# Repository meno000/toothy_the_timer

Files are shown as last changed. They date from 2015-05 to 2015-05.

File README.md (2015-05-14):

# toothy_the_timer
A little PCB project that helps kids brush teeth for the proper amount of time.

It uses the Atmet Attiny85 along with some shift registers and various LEDs, etc.

Schematics were created in KiCad. Gerbers are available if you'd like to send the board out to a fab house.

Note that this repository does not have a bootloader in it. You'll have to find/roll your own. This is mainly to avoid any issues with USB VID/PID numbers.

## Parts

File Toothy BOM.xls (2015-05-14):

Item # | Description | SMD or Through Hole | Mouser Part # | Mouser Mfg | Mouser Mfg Part # | Mouser $ | Digikey Part # | Digikey Mfg | Digikey Mfg # | Digikey $ | Distributor Selected | Quantity | Cost | Total Cost
PCB | PCB | N/A | N/A | N/A | N/A |  | N/A | N/A | N/A |  | DirtyPCBs | 1 | $2.50 | $2.50
Switches | Push Button Switches | SMD | 653-B3FS-1000 | Omron | B3FS-1000 | 0.455 | SW423CT-ND |  |  |  | Mouser | 3 | $0.46 | $1.36
USB | Micro USB Port - Female | SMD | 587-690-005-299-143 | EDAC | 690-005-299-143 | 0.198 |  |  |  |  | Mouser | 1 | $0.20 | $0.20
Diode | Power Diode | SMD | 625-RS1A-E3/5AT | Vishay | RS1A-E3/5AT | 0.99 |  |  |  |  | Mouser | 1 | $0.99 | $0.99
Capacitor | 10 uF | SMD | 77-VJ1206V106ZXQTBC | Vishay | VJ1206V106ZXQTW1BC | 0.049 |  |  |  |  | Mouser | 1 | $0.05 | $0.05
Capacitor | .1 uF | SMD | 77-VJ1206Y104KXXCBC | Vishay | VJ1206Y104KXXCW1BC | 0.033 |  |  |  |  | Mouser | 1 | $0.03 | $0.03
LED Resistor | 220 Ohm | SMD | 71-CRCW1206J-220-E3 | Vishay | CRCW1206220RJNEA | 0.008 |  |  |  |  | Mouser | 25 | $0.01 | $0.20
Pull Up Resistor | 10 kOhm | SMD | 71-CRCW1206J-10K-E3 | Vishay | CRCW120610K0JNEA | 0.03 |  |  |  |  | Mouser | 4 | $0.03 | $0.12
Attiny 85 | SOIC-8 Package | SMD | 556-ATTINY85-20SU | Atmel | ATtiny85-20SU | 1.22 |  |  |  |  | Mouser | 1 | $1.22 | $1.22
595 Shift | TSSOP/SOT-403 Package | SMD | 771-HC595PW112 | NSP | 74HC595PW,112 | 0.369 |  |  |  |  | Mouser | 3 | $0.37 | $1.11
ICSP Connection | 3x2 6 pin package | Through Hole | 517-30306-6002HB | 3M | 30306-6002HB | 0.52 |  |  |  |  | Mouser | 1 | $0.52 | $0.52
Regulator | 7805 LDO, .800 A. SOT-223 | SMD | 511-LD1117S50 | ST Micro | LD1117S50TR | 0.372 |  |  |  |  | Mouser | 1 | $0.37 | $0.37
LEDs | Various colors, 1206 | SMD | Various | Various | Various | 0.008 | Various | Various | Various | Various | Mouser | 25 | $0.01 | $0.20
Battery Connection | 2 pin | Through Hole | 538-70553-0036 | Molex | 70553-0036 | 0.633 |  |  |  |  | Mouser | 1 | $0.63 | $0.63
Battery Wire Connection | 2 pin | N/A | 538-50-57-9402 | Molex | 50-57-9402 | 0.293 |  |  |  |  | Mouser | 1 | $0.29 | $0.29
Crimp Terminal | 2 pin | N/A | 538-16-02-0096 | Molex | 16-02-0096 | 0.069 |  |  |  |  | Mouser | 2 | $0.07 | $0.14
Battery Pack | Battery Snap for 9V | N/A | 121-0424/I-GR | Eagle Plastic | 121-0424/I-GR | 0.39 |  |  |  |  | Mouser | 1 | $0.39 | $0.39
 |  |  |  |  |  |  |  |  |  |  |  |  | Total | $10.33
LEDs | Notes
Pink
Red | 1.8V, Need 220 Ohm R |  | 720-LHN974-KN-1 | Osram | LH N974-KN-1 | 0.08
Blue | 3V, Need 100 Ohm R |  | 859-LTST-C21TBKT | Liteon | LTST-C21TBKT | 0.16
Green | 2.6V |  | 720-LGN971-KN-1 | Osram | LG N971-KN-1
Purple
 |  |  | 121-0424/I-GR |  | 538-16-02-0096
 |  |  | Manufacturer Part #: |  | Manufacturer Part #:
 |  |  | 121-0424/I-GR |  | 16-02-0096

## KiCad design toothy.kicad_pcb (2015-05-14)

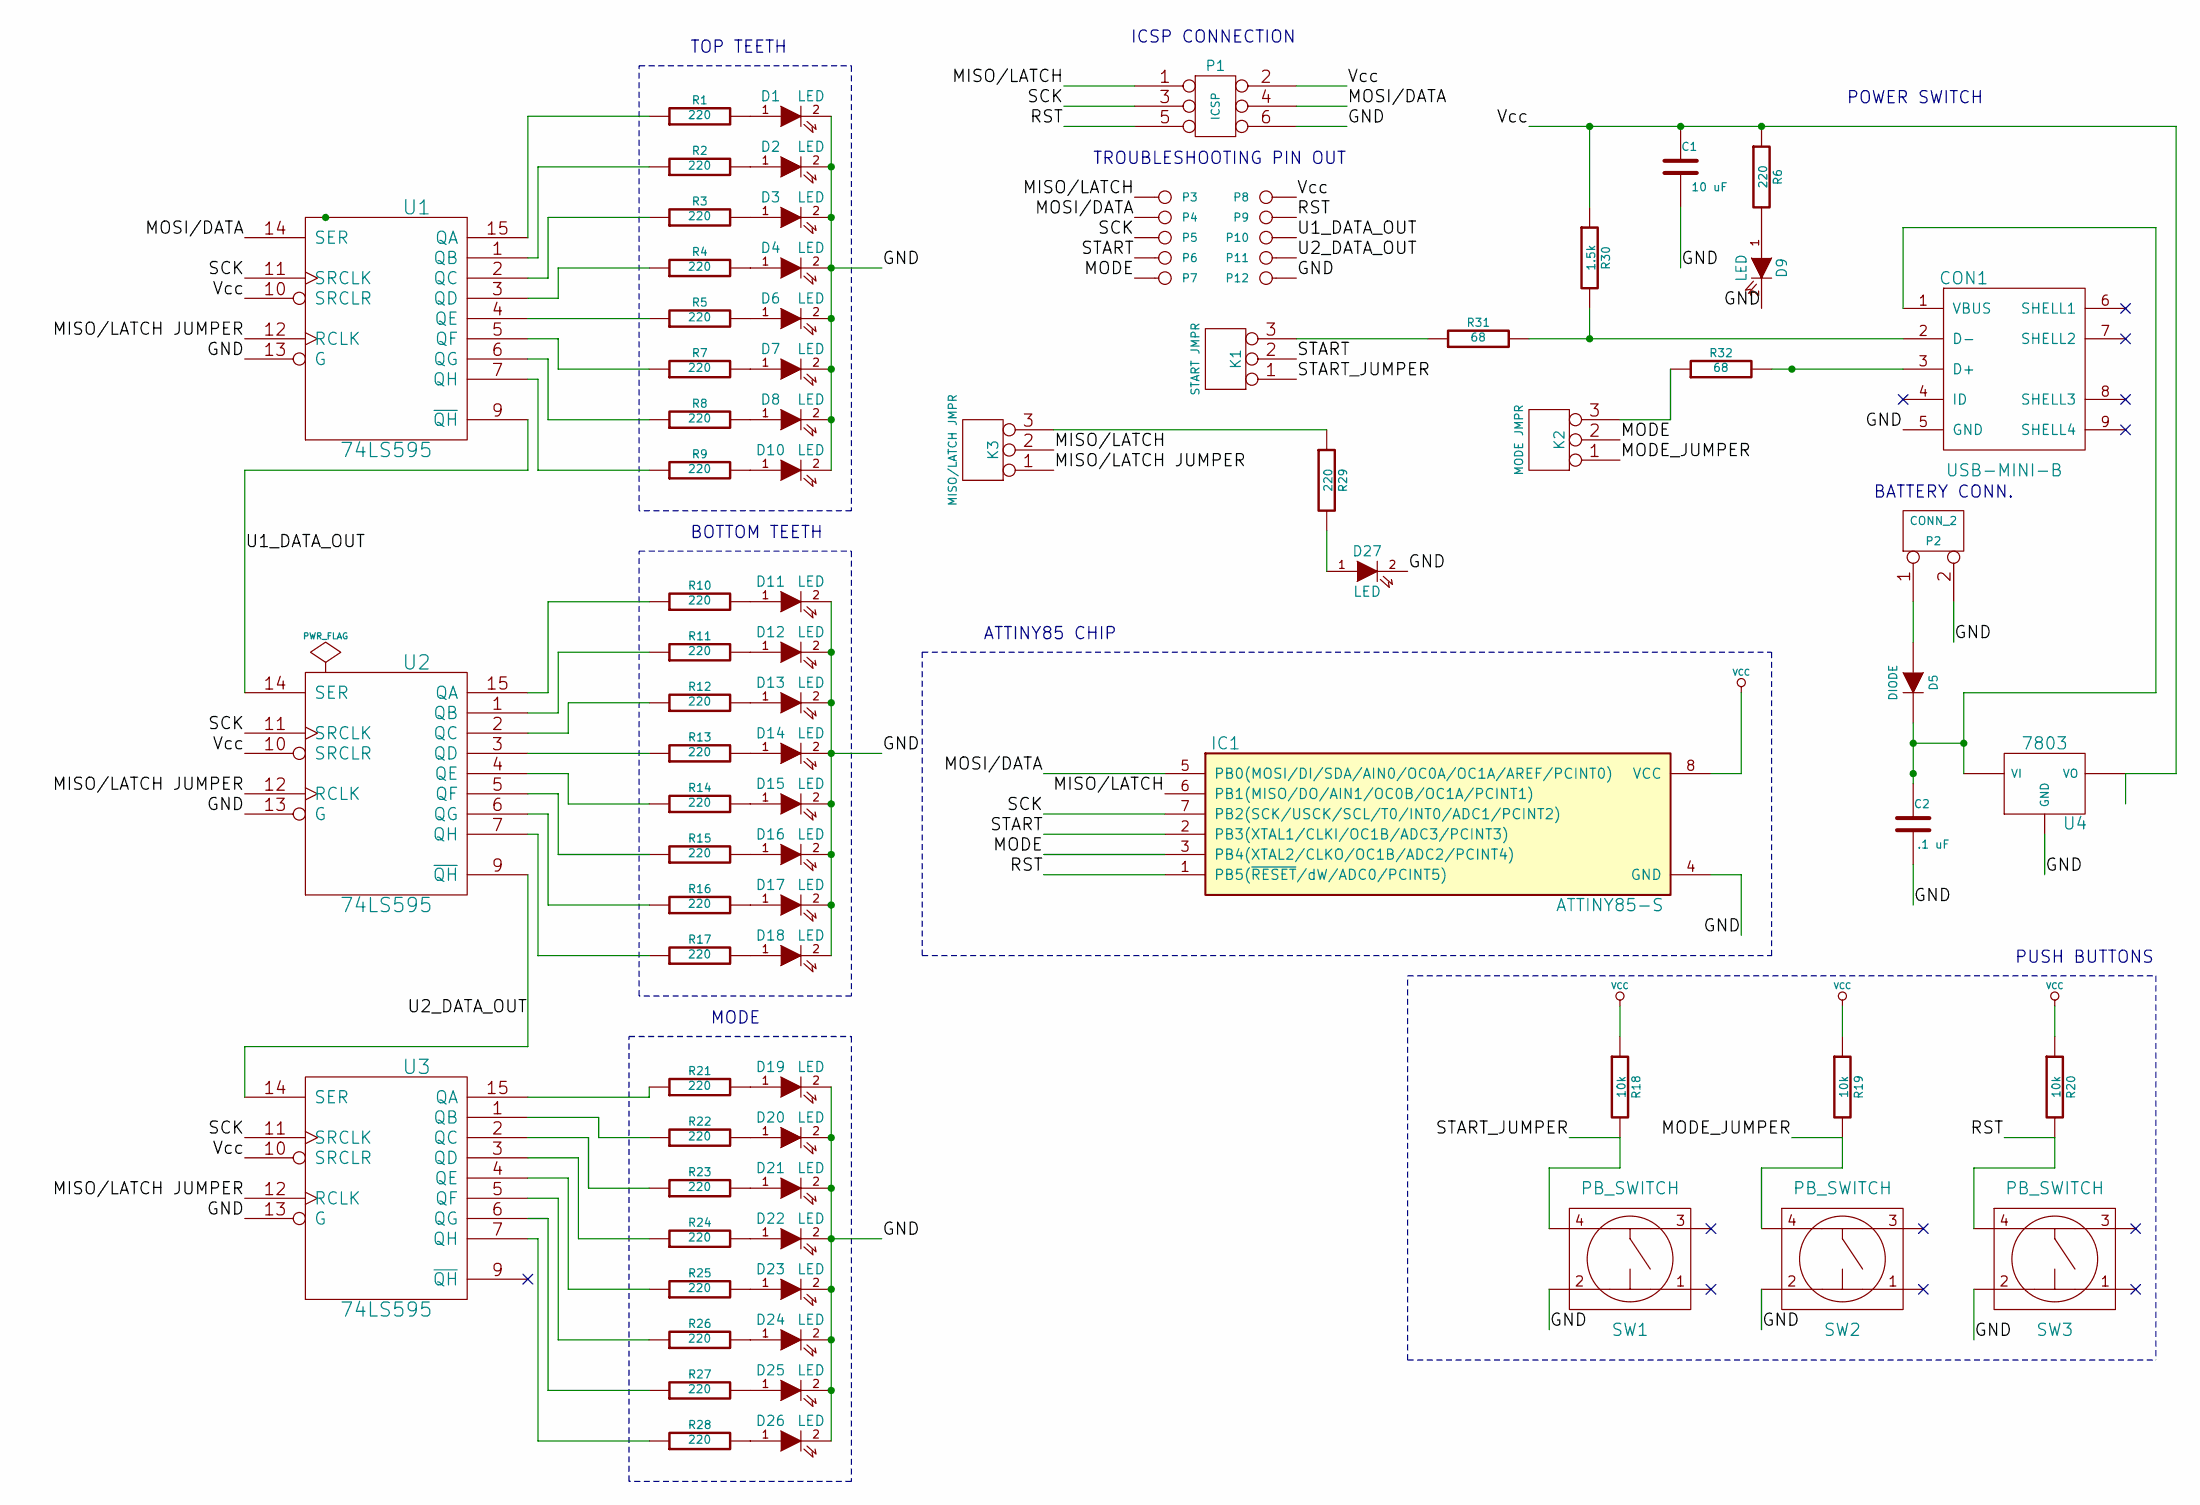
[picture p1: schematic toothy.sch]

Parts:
C1: 10 uF
C2: .1 uF
CON1: USB-MINI-B
D1, D2, D3, D4, D6, D7, D8, D9, D10, D11, D12, D13, D14, D15, D16, D17, D18, D19, D20, D21, D22, D23, D24, D25, D26, D27: LED
D5: DIODE
IC1: ATTINY85-S; SO8-200
K1: START JMPR
K2: MODE JMPR
K3: MISO/LATCH JMPR
P1: ICSP
P2: CONN_2
P3, P4, P5, P6, P7, P8, P9, P10, P11, P12: CONN_1
R1, R2, R3, R4, R5, R6, R7, R8, R9, R10, R11, R12, R13, R14, R15, R16, R17, R21, R22, R23, R24, R25, R26, R27, R28, R29: 220
R18, R19, R20: 10k
R30: 1.5k
R31, R32: 68
SW1, SW2, SW3: PB_SWITCH
U1, U2, U3: 74LS595
U4: 7803

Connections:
/MISO/LATCH: IC1.6 (PB1(MISO/DO/AIN1/OC0B/OC1A/PCINT1)), K3.2 (PM), P1.1, P3.1
/MISO/LATCH JUMPER: K3.1, U1.12 (RCLK), U2.12 (RCLK), U3.12 (RCLK)
/MODE: IC1.3 (PB4(XTAL2/CLKO/OC1B/ADC2/PCINT4)), K2.2 (PM), P7.1
/MODE_JUMPER: K2.1, R19.2, SW2.4
/MOSI/DATA: IC1.5 (PB0(MOSI/DI/SDA/AIN0/OC0A/OC1A/AREF/PCI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), P1.4, P4.1, U1.14 (SER)
/RST: IC1.1 (PB5(~RESET~/dW/ADC0/PCINT5)), P1.5, P9.1, R20.2, SW3.4
/SCK: IC1.7 (PB2(SCK/USCK/SCL/T0/INT0/ADC1/PCINT2)), P1.3, P5.1, U1.11 (SRCLK), U2.11 (SRCLK), U3.11 (SRCLK)
/START: IC1.2 (PB3(XTAL1/CLKI/OC1B/ADC3/PCINT3)), K1.2 (PM), P6.1
/START_JUMPER: K1.1, R18.2, SW1.4
/U1_DATA_OUT: P10.1, U1.9 (~QH), U2.14 (SER)
/U2_DATA_OUT: P11.1, U2.9 (~QH), U3.14 (SER)
GND: C1.2, C2.2, CON1.5 (GND), D1.2 (K), D2.2 (K), D3.2 (K), D4.2 (K), D6.2 (K), D7.2 (K), D8.2 (K), D9.2 (K), D10.2 (K), D11.2 (K), D12.2 (K), D13.2 (K), D14.2 (K), D15.2 (K), D16.2 (K), D17.2 (K), D18.2 (K), D19.2 (K), D20.2 (K), D21.2 (K), D22.2 (K), D23.2 (K), D24.2 (K), D25.2 (K), D26.2 (K), D27.2 (K), IC1.4 (GND), P1.6, P2.2 (PM), P12.1, SW1.2, SW2.2, SW3.2, U1.8 (GND), U1.13 (G), U2.8 (GND), U2.13 (G), U3.8 (GND), U3.13 (G), U4.GND
unnamed: D27.1 (A), R29.2
unnamed: CON1.2 (D-), R30.2, R31.2
unnamed: K2.3, R32.1
unnamed: D5.1 (A), P2.1
unnamed: K3.3, R29.1
unnamed: K1.3, R31.1
unnamed: R1.1, U1.15 (QA)
unnamed: R2.1, U1.1 (QB)
unnamed: R3.1, U1.2 (QC)
unnamed: R4.1, U1.3 (QD)
unnamed: C2.1, CON1.1 (VBUS), D5.2 (K), U4.VI
unnamed: CON1.3 (D+), R32.2
unnamed: R15.1, U2.5 (QF)
unnamed: R16.1, U2.6 (QG)
unnamed: R17.1, U2.7 (QH)
unnamed: R21.1, U3.15 (QA)
unnamed: R22.1, U3.1 (QB)
unnamed: R23.1, U3.2 (QC)
unnamed: R24.1, U3.3 (QD)
unnamed: R25.1, U3.4 (QE)
unnamed: R26.1, U3.5 (QF)
unnamed: R27.1, U3.6 (QG)
unnamed: R28.1, U3.7 (QH)
unnamed: R5.1, U1.4 (QE)
unnamed: R7.1, U1.5 (QF)
unnamed: R8.1, U1.6 (QG)
unnamed: R9.1, U1.7 (QH)
unnamed: R10.1, U2.15 (QA)
unnamed: R11.1, U2.1 (QB)
unnamed: R12.1, U2.2 (QC)
unnamed: R13.1, U2.3 (QD)
unnamed: R14.1, U2.4 (QE)
unnamed: D1.1 (A), R1.2
unnamed: D10.1 (A), R9.2
unnamed: D8.1 (A), R8.2
unnamed: D7.1 (A), R7.2
unnamed: D6.1 (A), R5.2
unnamed: D4.1 (A), R4.2
unnamed: D3.1 (A), R3.2
unnamed: D2.1 (A), R2.2
unnamed: D26.1 (A), R28.2
unnamed: D25.1 (A), R27.2
unnamed: D24.1 (A), R26.2
unnamed: D23.1 (A), R25.2
unnamed: D22.1 (A), R24.2
unnamed: D21.1 (A), R23.2
unnamed: D20.1 (A), R22.2
unnamed: D19.1 (A), R21.2
unnamed: D14.1 (A), R13.2
unnamed: D13.1 (A), R12.2
unnamed: D12.1 (A), R11.2
unnamed: D11.1 (A), R10.2
unnamed: D9.1 (A), R6.2
unnamed: D18.1 (A), R17.2
unnamed: D17.1 (A), R16.2
unnamed: D16.1 (A), R15.2
unnamed: D15.1 (A), R14.2
VCC: C1.1, IC1.8 (VCC), P1.2, P8.1, R6.1, R18.1, R19.1, R20.1, R30.1, U1.10 (SRCLR), U1.16 (VCC), U2.10 (SRCLR), U2.16 (VCC), U3.10 (SRCLR), U3.16 (VCC), U4.VO

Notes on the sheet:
TOP TEETH
BOTTOM TEETH
MODE
ATTINY85 CHIP
PUSH BUTTONS
ICSP CONNECTION
POWER SWITCH
BATTERY CONN.
TROUBLESHOOTING PIN OUT

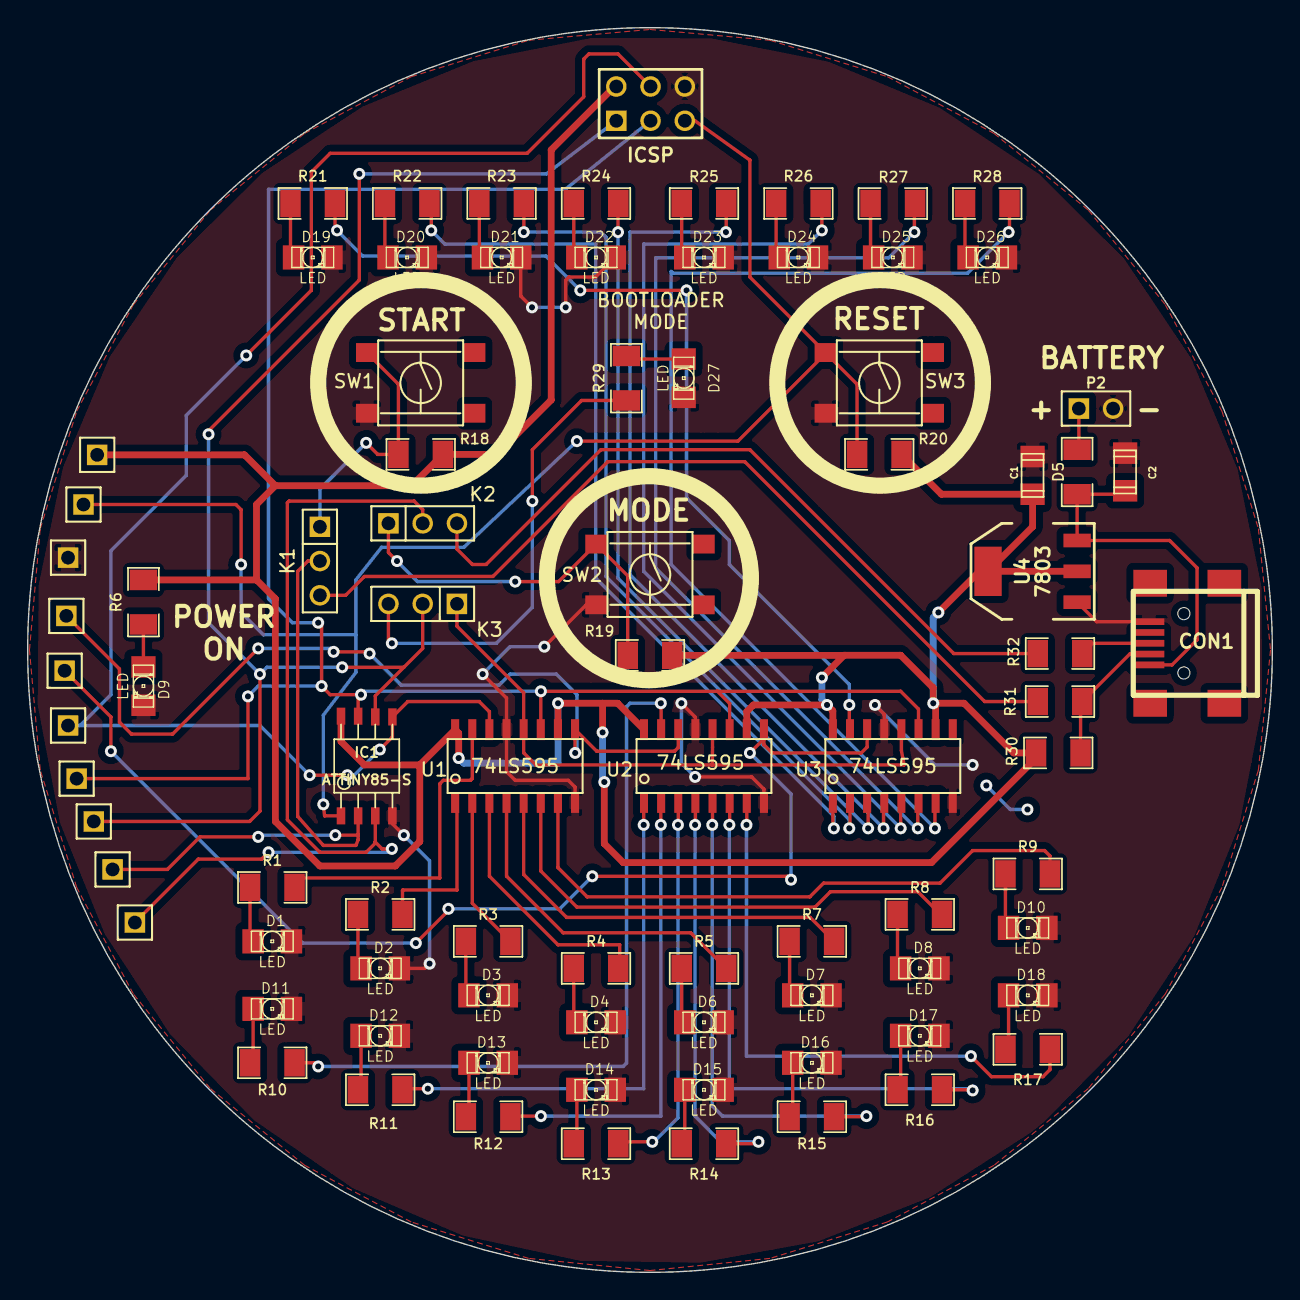
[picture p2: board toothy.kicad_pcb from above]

Board: 2 copper layers, 92.3 x 92.3 mm, 85 parts (0 on the bottom side), 70 nets.

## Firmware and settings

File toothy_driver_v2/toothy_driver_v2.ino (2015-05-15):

;// Toothy Driver ver 2
// by Christian M. Restifo
// 4/23/15

// This original code in this software is released under the CC 1.0 License
// Note that this software may use libraries released under other licenses which apply to those libraries only

// Pin configuration for ATTINY85. Configure as necessary for your system if different

// First we include some stuff we'll need for later

#include <avr/power.h>
#include <Bounce2.h>

// Pin definitions for ATTiny85. Alter as necessary if you use another chip.

// Pin connected to ST_CP of 74HC595
int latchPin = 1;

// Pin connected to SH_CP of 74HC595
int clockPin = 2;

// Pin connected to DS of 74HC595
int dataPin = 0;

int startPin = 3;
int modePin = 4;

// Debouncing stuff for input switches

Bounce startPinbouncer = Bounce();
Bounce modePinbouncer = Bounce();

// Various variables we'll need for later

int numRegisters = 3;       // number of shift registers we're using 
int registerArray[] = {0, 1, 2}; // for the 3 595 shift registers. 0 is the mode, 1 is bottom teeth, 2 is top.
// the first 595 is top teeth so we shift to that one *last*.
int brushTime = 30000; // brush time for each section in milliseconds
int delayTime; // delay while flashing
int left, left1, right, right1; // used to hold the patterns we'll flash
int numFlashCycles; // each cycle is two delay times (on and off)
int countdown_delay = 500; // countdown speed
int z;
int mode = 1; // start off with first mode
int start;
boolean mode_change; // keeps track if mode has changed
int mode_select; // holds value of mode pin status

void setup() {
    if (F_CPU==16000000) clock_prescale_set(clock_div_1); // used for running at 16 MHz
  //set pins to output so you can control the shift register
  pinMode(latchPin, OUTPUT);
  pinMode(clockPin, OUTPUT);
  pinMode(dataPin, OUTPUT);
  pinMode(startPin, INPUT);
  pinMode(modePin, INPUT);
  startPinbouncer.attach(startPin);
  startPinbouncer.interval(100);
  modePinbouncer.attach(modePin);
  modePinbouncer.interval(100);
  // clear registers and start up
  resetData();
  flushData(registerArray);
  delay(100);
  startup_smile();
  delay(1000);
  resetData();
  registerArray[0] = mode; // start with mode 1
  flushData(registerArray);
}

void loop() {

  start = digitalRead(startPin);

  if (start == LOW) {    // if button has been pressed, brush teeth
    countdown();
    brush(mode);
    while (mode_change == false) {      // randomly flash lights to indicate time is up until mode button is pressed
      registerArray[2] = random(0, 255);
      registerArray[1] = random(0, 255);
      flushData(registerArray);
      delay(100);
      if (digitalRead(modePin) == LOW){
        mode_change = true;  
      }
    }
    resetData();
    registerArray[0] = mode;
    flushData(registerArray);
  }

  mode_change = modePinbouncer.update();
  int mode_select = modePinbouncer.read();
  if (mode_select == LOW && mode_change == true) { // advance the mode if the button is pressed
    if (mode == 128) { // loop back to beginning if at end
      mode = 1;
    }
    else {
      mode = mode << 1; // shift left 1 or multiply by 2
    }
    registerArray[0] = mode;
    flushData(registerArray);
  }

}

void brush(int mode) {

    // Constructs the flashing patterns. Note that for the first four, we call a subroutine to send the data out since it's fairly simple
    // The other patterns are sent out here due to their complexity
    // How the first three (left, left1, right, right1) work:
    
    // left and left1 is a full integer constructed such that only the 4 left (ie, MSB leds) are lit.
    // right and right1 are set up so that the first four are on and the 4 right LEDs flash in the proper manner
    // Example:
    // Bits => 0    1    2    3    4    5    6    7
    //         1    1    1    1    0    0    0    0  => evalutes to 15. So if left (or left1) is set to 15, those four will turn on.
    //         1    1    1    1    0    0    1    1  => evaluates to 207. This will turn on all left LEDs and the two far right LEDs
    
    // The patterns below are called from here. This is for stuff like the Larson scanner effect
    
    int pattern[] = {7, 14, 13, 11};        // snake pattern for left
    int pattern2[] = {123, 239, 223, 177};  // snake pattern for right
    int pattern3[] = {11, 13, 14, 7};       // reverse snake pattern for left
    int pattern4[] = {177, 239, 223, 177};  // reverse snake pattern for right
    int pattern5[] = {1, 2, 4, 8, 4, 2};        // larson 
    int pattern6[] = {31, 47, 79, 143, 79, 47}; // larson
  
  switch (mode) {

    case 1:  // flashes each section while counting down
      delayTime = 25; // delay while flashing
      numFlashCycles = brushTime / (delayTime * 2); // each cycle is two delay times (on and off)
      left = 15;
      left1 = 0;
      right = 255;
      right1 = 15;
      createPattern(left, left1, right, right1);
      break;

    case 2:   // alternately flashes 2 LEDs out of the 4
      delayTime = 250; // delay while flashing
      numFlashCycles = brushTime / (delayTime * 2); // each cycle is two delay times (on and off)
      left = 3;
      left1 = 12;
      right = 63;
      right1 = 207;
      createPattern(left, left1, right, right1);
      break;

    case 4:   // alternately flashes 2 LEDs out of the 4. Similar to case 2 but with different pattern
      brushTime = 30000; // brush time for each section in seconds
      delayTime = 250; // delay while flashing
      numFlashCycles = brushTime / (delayTime * 2); // each cycle is two delay times (on and off)
      left = 9;
      left1 = 6;
      right = 159;
      right1 = 111;
      createPattern(left, left1, right, right1);
      break;

    case 8:   // Does a "run" of the 4 LEDs
      delayTime = 50; // delay while flashing
      numFlashCycles = brushTime / (delayTime); // Each cycle is one flash since we're only illuminating one LED at a time
      for (int x = numRegisters - 1; x >= 1; x--) { // count through the top and bottom registers. Go in reverse because of the way we shift out
        registerArray[x] = 1;
        for (int y = 0; y < numFlashCycles; y++) {
          flushData(registerArray);
          delay(delayTime);
          registerArray[x] = registerArray[x] << 1; // left shift to multiply by 2
          if (registerArray[x] == 16) {
            registerArray[x] = 1;
          }
        }
        int temp = 16;
        for (int y = 0; y < numFlashCycles; y++) {
          registerArray[x] = 15 | temp;
          flushData(registerArray);
          delay(delayTime);
          temp = temp << 1; // left shift to multiply by 2
          if (temp == 256) {
            temp = 16;
          }
        }
        registerArray[x] = 255;  // set all top teeth to "on" while processing bottom row
      }
      break;

    case 16:   // Random illumination of 4 LEDs
      delayTime = 25; // delay while flashing
      numFlashCycles = brushTime / (delayTime); // Each cycle is one flash since we're only illuminating one number at a time
      for (int x = numRegisters - 1; x >= 1; x--) { // count through the top and bottom registers. Go in reverse because of the way we shift out
        registerArray[x] = 1;
        for (int y = 0; y < numFlashCycles; y++) {
          registerArray[x] = random(0, 15);  // flash random 4 LEDS
          flushData(registerArray);
          delay(delayTime);
        }
        for (int y = 0; y < numFlashCycles; y++) {
          registerArray[x] = 15 | random(16, 255); // we use | with 15 to make sure first 4 LEDs stay on
          flushData(registerArray);
          delay(delayTime);
        }
        registerArray[x] = 255;  // set all top teeth to "on" while processing bottom row
      }
      break;


    case 32:   // Snake pattern
      delayTime = 200; // delay while flashing
      numFlashCycles = brushTime / (delayTime); // Each cycle is one flash since we're only illuminating one number at a time
      z = 0;
      for (int x = numRegisters - 1; x >= 1; x--) { // count through the top and bottom registers. Go in reverse because of the way we shift out
        registerArray[x] = 1;
        for (int y = 0; y < numFlashCycles; y++) {
          registerArray[x] = pattern[z];   // pick LED from pattern
          flushData(registerArray);
          delay(delayTime);
          z = z + 1;
          if (z == 4) {
            z = 0;
          }
        }
        for (int y = 0; y < numFlashCycles; y++) {
          registerArray[x] = pattern2[z];   // pick LED from pattern
          flushData(registerArray);
          delay(delayTime);
          z = z + 1;
          if (z == 4) {
            z = 0;
          }
        }
        registerArray[x] = 255;  // set all top teeth to "on" while processing bottom row
      }
      break;

    case 64:   // Reverse snake
      delayTime = 200; // delay while flashing
      numFlashCycles = brushTime / (delayTime); // Each cycle is one flash since we're only illuminating one number at a time

      z = 0;
      for (int x = numRegisters - 1; x >= 1; x--) { // count through the top and bottom registers. Go in reverse because of the way we shift out
        registerArray[x] = 1;
        for (int y = 0; y < numFlashCycles; y++) {
          registerArray[x] = pattern3[z];   // pick LED from pattern
          flushData(registerArray);
          delay(delayTime);
          z = z + 1;
          if (z == 4) {
            z = 0;
          }
        }
        for (int y = 0; y < numFlashCycles; y++) {
          registerArray[x] = pattern4[z];   // pick LED from pattern
          flushData(registerArray);
          delay(delayTime);
          z = z + 1;
          if (z == 4) {
            z = 0;
          }
        }
        registerArray[x] = 255;  // set all top teeth to "on" while processing bottom row
      }
      break;

    case 128:   // Larson scanner pattern
      delayTime = 100; // delay while flashing
      numFlashCycles = brushTime / (delayTime); // Each cycle is one flash since we're only illuminating one number at a time
      z = 0;
      for (int x = numRegisters - 1; x >= 1; x--) { // count through the top and bottom registers. Go in reverse because of the way we shift out
        registerArray[x] = 1;
        for (int y = 0; y < numFlashCycles; y++) {
          registerArray[x] = pattern5[z];   // pick LED from pattern
          flushData(registerArray);
          delay(delayTime);
          z = z + 1;
          if (z == 6) {
            z = 0;
          }
        }
        for (int y = 0; y < numFlashCycles; y++) {
          registerArray[x] = pattern6[z];   // pick LED from pattern
          flushData(registerArray);
          delay(delayTime);
          z = z + 1;
          if (z == 6) {
            z = 0;
          }
        }
        registerArray[x] = 255;  // set all top teeth to "on" while processing bottom row
      }
      break;

  }


}

void createPattern(int left, int left1, int right, int right1) { // sends the pattern selected by brush procedure to LEDs
  for (int x = numRegisters - 1; x >= 1; x--) { // count through the top and bottom registers. Go in reverse because of the way we shift out
    for (int y = 0; y < numFlashCycles; y++) {
      registerArray[x] = left;   // flash first 4 LEDS
      flushData(registerArray);
      delay(delayTime);
      registerArray[x] = left1;
      flushData(registerArray);
      delay(delayTime);
    }
    for (int y = 0; y < numFlashCycles; y++) {
      registerArray[x] = right; //flash second set of LEDS with first 4 "on"
      flushData(registerArray);
      delay(delayTime);
      registerArray[x] = right1;
      flushData(registerArray);
      delay(delayTime);
    }
    registerArray[x] = 255;  // set all top teeth to "on" while processing bottom row
  }
}


void flushData(int bytesToPush[]) { // shifts out the data to the registers
  digitalWrite(latchPin, LOW);
  for (int x = 0; x < numRegisters; x++) {
    shiftOut(dataPin, clockPin, MSBFIRST, bytesToPush[x]);
  }
  digitalWrite(latchPin, HIGH);
}

void countdown() {  // counts down to start brushing. lights top teeth LEDS and does a countdown
  int x = 255;
  while (x >= 1) {
    registerArray[2] = x;
    flushData(registerArray);
    x = x >> 1; // shift one to the right or divide by two
    delay(countdown_delay);
  }
}

void resetData() { // clears all registers so that all LEDs are off
  for (int x = 0; x < numRegisters; x++) {
    registerArray[x] = 0;
  }
}

void startup_smile() { // 'smiles' with the leds on startup
  int smile_pattern[] = {0,24,60,126,255}; // starts are middle two LEDs and works outwards on both sides
  for (int z = 0; z <= 3; z++) {
    for (int y = 0; y <= 4; y++) {
      for (int x = 0; x < numRegisters; x++) {
        registerArray[x] = smile_pattern[y];
      }
      flushData(registerArray);
      delay(100);
    }  
  }
  
}
